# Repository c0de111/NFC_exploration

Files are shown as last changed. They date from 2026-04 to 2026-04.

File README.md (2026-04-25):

# NFC exploration

Sandbox repo to explore **ST25DV04KC (ISO15693 / NFC-V)** tap-to-trigger flows for power control and waking circuits such as inki.

## Goal
Build a small, reproducible test platform (ST25DV04KC + **Raspberry Pi Pico/RP2040** + antenna + simple enclosure) to validate:
- RF-field / `V_EH` wake behavior in the real case
- Phone → tag writes (EEPROM / Type 5)
- MCU reads request over I²C and clears/acks
- End-to-end timing assumptions for a future “tap-to-book” workflow

## Current validated behavior
- ST25DV04KC bring-up over I2C is stable on Pico (`GP20/GP21`), with ST25 power switched by `GP18`.
- End-to-end NFC-V write from phone to tag user memory is working.
- Firmware parses 16-byte `INKI` request payloads from the last user-memory slot (`0x01F0` on ST25DV04KC).
- Firmware command opcode handling is active:
  - `0x11` -> `LED1` slow blink
  - `0x12` -> `LED1` fast blink (same onboard LED)
  - `0x01` -> legacy alias mapped to `LED1` slow blink
- Incomplete/invalid `INKI` frames are ignored (to avoid partial-write races).
- Valid requests are cleared only after `RF field` goes `OFF` (reduces interference with phone-side readback).
- Power latch is asserted early by Pico on boot (`GP28`) and auto-released after `NFC_AUTO_POWER_OFF_MS` (default `10000` ms).
- Runtime logging is event-driven: startup diagnostics once, then RF field edges and request actions only.

## Tuning firmware (antenna / power characterization)
A dedicated firmware (`nfc_tune`, source: `firmware/src/tune_main.c`) for real-time RF energy-harvesting characterization. It samples the ST25DV `V_EH` output via Pico ADC and renders a live scrolling bar graph in the terminal showing harvested power delta above baseline.

### What it measures
- ADC voltage on `V_EH` pin (default ADC1 = `GP27`), averaged and EMA-smoothed
- Delta above a startup baseline capture (no-RF reference)
- RF field state derived from voltage thresholds (configurable ON/OFF hysteresis)
- ST25 EH control register state (`EH_EN`, `EH_ON`, `FIELD_ON`, `VCC_ON`) via I2C

### Build and flash
```bash
make firmware-tune                    # build nfc_tune
# then either:
make firmware-tune-flash              # flash via SWD
# or drag-and-drop firmware/build/nfc_tune.uf2 in BOOTSEL mode
```

### Tuning workflow
1. Connect Pico via USB (serial + power).
2. Open terminal: `sudo tio /dev/ttyACM0`
3. Wait for baseline capture (keep RF away for ~2 seconds at boot).
4. Tap phone to antenna — the live graph shows `V_EH` delta in mV, RF ON/OFF transitions, session peak, and EH register state.
5. Adjust antenna matching (C2/C3 on `NFC_harness_V0`) and re-tap to compare coupling.
6. `Ctrl+C` to stop.

### Key CMake tuning parameters
All defaults are in `firmware/CMakeLists.txt`:
- `NFC_TUNE_ADC_INPUT` – ADC channel (default `1` = `GP27`)
- `NFC_TUNE_FIELD_ON_MV` / `NFC_TUNE_FIELD_OFF_MV` – RF detection hysteresis thresholds (default `9` / `4` mV)
- `NFC_TUNE_GRAPH_WIDTH` / `NFC_TUNE_GRAPH_HEIGHT` – terminal graph dimensions (default `72x20`)
- `NFC_TUNE_GRAPH_MAX_MV` – vertical scale (default `3000` mV)
- `NFC_TUNE_SAMPLE_COUNT` / `NFC_TUNE_REPORT_INTERVAL_MS` – samples per report and update rate

## Current Wake/Latch Circuitry (PCB: `NFC_harness_V0`)
- `Q1` (`TSM260P02CX`, P-MOS) is the high-side power switch:
  - source -> `Vbatt`
  - drain -> Pico `VSYS`
- ST25 `GPO_(OPEN_DRAIN)` and the `Q1` gate share the same control net (wake/power-on net).
- Gate network shaping:
  - `R4=1M` pull-up to `Vbatt`
  - `C5=22n` to GND (pulse shaping / hold)
- Pico latch-hold path:
  - Pico `GPIO28` (`NFC_POWER_HOLD_PIN`) -> `R5=100k` -> `Q2` base
  - `R9=50k` pulls base to GND
  - `Q2` collector also sinks the same gate-control net
- On this PCB revision, Pico `GPIO19` is unconnected.
- LED wiring status on this PCB revision:
  - Both blink commands (`0x11` slow, `0x12` fast) use the firmware power-LED output (onboard Pico/Pico W path).
  - `NFC_STATUS_LED_PIN` (default `GP15`) is currently not routed to a dedicated onboard LED footprint here (external LED/wire may be needed).

## Command Flow (Phone -> ST25 -> Pico)
1. Board is fully off (`Vbatt` connected, no USB, Pico unpowered).
2. Phone tap powers ST25 RF side and writes the 16-byte `INKI` payload (including opcode byte) over NFC-V into ST25 EEPROM, while Pico can still be fully off.
3. ST25 asserts `GPO` low on configured wake event (`RF_WRITE`), pulling `Q1` gate low and powering Pico.
4. Pico boots and immediately asserts `GPIO28` high to latch power through `Q2`.
5. Data transfer from ST25 to Pico happens after boot over I2C (not on GPO):
   - Pico powers ST25 VCC via `GP18`
   - firmware reads request bytes from the last ST25 user-memory slot
6. Firmware validates the payload, applies opcode behavior, queues clear for RF-OFF, and later clears the slot.
7. Firmware releases the latch after timeout (`NFC_AUTO_POWER_OFF_MS`, default `10000` ms; re-armed on accepted commands).

Note:
- Runtime-loop request processing still runs while RF field is ON, with clear deferred to RF field OFF.
- Additionally, at boot firmware now checks for a stored valid request. If RF field is already OFF, it applies the command immediately and clears it at boot.
- If no valid `INKI` request is found after wake and RF is already OFF, firmware releases the power latch immediately.

## Repository layout
- `docs/context.md` – running notes, decisions, history, and solved problems
- `firmware/` – Pico SDK firmware scaffold (RP2040) for ST25 I²C exploration  
  - `src/` app entry (`main.c` harness, `tune_main.c` tuning) and bus adapter
  - `third_party/st25dv/` vendored ST25DV driver (git subtree)  
  - `scripts/` build/flash/reset helpers  
  - `cmake/` Pico SDK import helper  
- `pcb/NFC_harness_V0/` – KiCad project (schematic, layout, CAM profile)
- `pcb/tools/run_pcb2gcode.sh` – shared pcb2gcode runner
- `pcb/components/` + `pcb/project-libraries/` – KiCad symbols/footprints (includes ST25DV package lib submodule)
- `datasheet/` – ST25DV04KC datasheet + app notes
- `android/` – NFC‑V test apps (writer + hello) *(not needed for Pico-only workflow)*

## Typical workflow (from repo root)
1) **Build firmware**: `make firmware` (uses `PICO_SDK_PATH`, default `$HOME/pico/pico-sdk`).
2) **Flash**:  
   - Drag‑and‑drop: copy `firmware/build/nfc_harness.uf2` to Pico in BOOTSEL mode, or  
   - SWD: `make firmware-flash` (OpenOCD + CMSIS-DAP).
3) **Iterate**: edit `firmware/src/main.c` (and future helpers), rebuild, and re‑flash.
4) **CAM / milling** (optional): `pcb/tools/run_pcb2gcode.sh -b NFC_harness_V0` to regenerate toolpaths.

## Build & flash (Pico / RP2040)

### Build
```bash
# from repo root (recommended)
make firmware

# or inside firmware/
cd firmware
./scripts/build.sh   # expects $PICO_SDK_PATH (defaults to $HOME/pico/pico-sdk)
```
More detail (pin overrides, UF2 path, picotool toggles): see `firmware/README.md`.

Notes:
- Picotool is disabled by default to avoid downloads. The build script auto-fetches `uf2conv.py` (Microsoft UF2 tool) on first run and converts `nfc_harness.bin` → `nfc_harness.uf2`.
- Set `-DPICO_NO_PICOTOOL=OFF` in `cmake` if you prefer the picotool UF2/signing path.

Clean build artifacts:
```bash
make clean   # removes firmware/build only
```

Flash options:
- **USB drag‑and‑drop**: copy `firmware/build/nfc_harness.uf2` to the Pico mass‑storage device (BOOTSEL).
- **SWD (OpenOCD + CMSIS‑DAP probe)**:
  ```bash
  cd firmware
  ./scripts/flash.sh
  ```

### Root make targets (quick reference)
- `make firmware` – configure & build firmware into `firmware/build/`
- `make firmware-tune` – build dedicated antenna tuning firmware (`nfc_tune`)
- `make firmware-flash` – flash over SWD (OpenOCD + CMSIS‑DAP)
- `make firmware-tune-flash` – flash tuning firmware ELF over SWD
- `make clean` – remove `firmware/build/` only

## CAM workflow (pcb2gcode)
From repo root:
```bash
pcb/tools/run_pcb2gcode.sh -b NFC_harness_V0
```
The profile lives at `pcb/NFC_harness_V0/cam/pcb2gcode/profiles/default.millprojects` and uses repo-relative paths.

## Quick RF test (phone + Pico)
1. Connect a loop antenna to `J3` (`AC0`/`AC1`) on the PCB.
2. Build and flash firmware:
   - `make firmware`
   - copy `firmware/build/nfc_harness.uf2` to Pico in BOOTSEL mode (or use SWD).
3. Open serial logs:
   - `sudo tio /dev/ttyACM0`
4. On phone, open the NFC-V app (`inki`):
   - pick command button: `LED1 Slow` or `LED2 Fast`
5. Tap phone to antenna and hold briefly.

Expected runtime log pattern:
- `RF field: ON`
- `Request@0x01F0: ...`
- `INKI request: version=... opcode=... duration_min=...`
- `Command applied: opcode=... -> ...`
- `Queued clear after RF field OFF`
- `RF field: OFF`
- `Cleared request after RF OFF (...)`
- `Auto power-off: GP28 -> LOW`

Sample serial log (successful run):
```text
[INFO] RF field: OFF
[INFO] RF field: ON
[INFO] Request@0x01F0: 49 4E 4B 49 01 11 3C 00 ...
[OK] INKI request: version=1 opcode=0x11 duration_min=60 unix=... nonce=...
[OK] Command applied: opcode=0x11 -> LED1 slow blink
[INFO] Queued clear after RF field OFF
[INFO] RF field: OFF
[OK] Cleared request after RF OFF (16 bytes @ 0x01F0, attempts=1, 8ms)
[WARN] Auto power-off: GP28 -> LOW
```

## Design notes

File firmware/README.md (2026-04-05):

# Firmware (Pico / RP2040)

Pico-only firmware scaffold for the NFC harness.

It uses:
- **Pico SDK** (external dependency): toolchain integration + RP2040 libs (`hardware_i2c`, `pico_stdlib`, UF2 generation, …).
- **ST25DV driver** (vendored code): ST’s `stm32-st25dv` sources live in `third_party/st25dv/` (git subtree).

The ST driver is **not** part of the Pico SDK. It’s compiled into the firmware and talks to the Pico SDK I²C API through a small adapter layer (`ST25DV_IO_t`) implemented in `src/main.c` and `src/tune_main.c`.

## Layout
```
firmware/
  src/               # app entrypoints + bus adapters (`main.c`, `tune_main.c`)
  include/           # project headers (empty placeholder for now)
  third_party/st25dv # vendored ST25DV driver (subtree)
  cmake/             # pico_sdk_import.cmake
  scripts/           # build/flash helpers
  build/             # generated (gitignored)
```

## Dependencies (host)
- CMake + Make/Ninja
- `arm-none-eabi-gcc` toolchain
- `pico-sdk` checkout on disk (default path: `$HOME/pico/pico-sdk`)

## Build
```bash
# from repo root
make firmware
make firmware-tune

# or inside firmware/
cd firmware
./scripts/build.sh
./scripts/build.sh --target tune
```

`scripts/build.sh` passes `NFC_AUTO_POWER_OFF_MS` into CMake; default is `10000` ms (override per build, e.g. `NFC_AUTO_POWER_OFF_MS=5000 make firmware`).
By default it builds `nfc_harness`; use `--target tune` to build `nfc_tune`.

Picotool is disabled by default to avoid fetching/building it. On first run the build script downloads `uf2conv.py` and `uf2families.json` (Microsoft UF2 tool) into `firmware/scripts/` and converts `<target>.bin` → `<target>.uf2` without picotool. To re-enable picotool-based UF2/signing instead, configure CMake with `-DPICO_NO_PICOTOOL=OFF -DPICO_NO_UF2=OFF`.

Clean build directory (no rebuild):
```bash
make clean
# or
cd firmware && ./scripts/build.sh --clean
```

You can override common settings via CMake cache variables:
```bash
cd firmware
cmake -S . -B build -DPICO_BOARD=pico_w -DNFC_I2C_SDA_PIN=20 -DNFC_I2C_SCL_PIN=21 -DNFC_STATUS_LED_PIN=15 -DNFC_POWER_HOLD_PIN=28 -DNFC_ST25_VCC_EN_PIN=18 -DNFC_ST25_POWER_ON_DELAY_MS=10 -DNFC_ENABLE_WAKE_GPO_CONFIG=1 -DNFC_ENABLE_STARTUP_DIAGNOSTICS=1 -DNFC_ENABLE_BOOT_RW_TIMING_TEST=1
cmake --build build -j
```

`NFC_POWER_LED_PIN` controls a dedicated power-indicator LED (default `25`, Pico onboard LED). It is set ON at boot and stays ON while firmware is running; set `-DNFC_POWER_LED_PIN=-1` to disable.
On `pico_w`, the onboard LED is not on RP2040 GPIO; firmware uses CYW43 LED control when built with `PICO_BOARD=pico_w`.

By default the firmware drives `NFC_ST25_VCC_EN_PIN` high (`GP18`) and waits `NFC_ST25_POWER_ON_DELAY_MS` before ST25 I2C accesses. Set `-DNFC_ST25_VCC_EN_PIN=-1` if ST25 VCC is always powered externally.
`NFC_POWER_HOLD_PIN` (default `28`) is asserted high very early at boot so external latch circuitry can keep the board powered after an NFC-triggered wake pulse.
`NFC_ENABLE_WAKE_GPO_CONFIG=1` configures ST25 GPO for wake source `RF_WRITE` and sets longest pulse (`IT_TIME=0`, ~302 us) during startup.
`NFC_WAKE_GPO_SELFTEST_STRICT=0` keeps startup `SELFTEST` non-fatal for transient wake-GPO boot configuration failures (recommended while validating real wake behavior). Set it to `1` if you want strict bring-up gating.
At boot it also runs diagnostics (I2C address probe, dynamic status registers, self-test summary). Set `-DNFC_ENABLE_STARTUP_DIAGNOSTICS=0` for production-style minimal boot logs. `NFC_ENABLE_BOOT_RW_TIMING_TEST=1` enables a one-shot request-slot write/read/restore timing test (auto-skipped if a live `INKI` request is present).
`NFC_AUTO_POWER_OFF_MS` controls automatic latch release timeout (default `10000` ms). Set `0` to disable automatic power-off.
`NFC_LED_SLOW_PERIOD_MS` and `NFC_LED_FAST_PERIOD_MS` control blink periods for command-driven LED modes.

## Flash
- **USB drag‑and‑drop**: copy `build/nfc_harness.uf2` (or `build/nfc_tune.uf2`) onto the Pico in BOOTSEL mode.
- **SWD (OpenOCD + CMSIS‑DAP probe)**:
  ```bash
  cd firmware
  ./scripts/flash.sh
  ./scripts/flash.sh ./build/nfc_tune.elf
  ```

## Tuning firmware (`nfc_tune`)
`nfc_tune` is a dedicated antenna-tuning build that keeps the main Android/tap flow untouched:
- Boots Pico and ST25 (`GP18` power enable).
- Enables ST25 energy harvesting mode (`EH_MODE=ACTIVE_AFTER_BOOT`, `EH_EN=ON`).
- Samples ADC continuously and performs live RF detection from `V_EH`:
  - Startup baseline capture (no RF expected).
  - EMA smoothing.
  - Hysteresis thresholds (`ON` / `OFF`) with debounce for stable field state.
  - Active EH enforcement: retries `EH_EN` enable at boot and periodically re-checks during runtime.
  - Runtime EH re-arm: if field is present but `EH_ON=0`, firmware re-arms EH and re-validates state.
  - Hard requirement at boot: firmware stops if `EH_EN` cannot be latched.
  - Per-session peak delta tracking to tune coil turns and trimmer.
  - ANSI color bar graph panel (`20` rows by default) updated in place with no terminal scroll.
  - Legacy single-line status remains below the graph (`RF/raw/v/ema/base/d/peak/sess/EH`).

Default tuning options:
- `NFC_TUNE_ADC_INPUT=1` (`GPIO27` / Pico pin `32` / ADC1)
- `NFC_TUNE_SAMPLE_COUNT=256`
- `NFC_TUNE_REPORT_INTERVAL_MS=100`
- `NFC_TUNE_SAMPLE_DELAY_US=20`
- `NFC_TUNE_EMA_ALPHA=0.50`
- `NFC_TUNE_BASELINE_SAMPLES=4000`
- `NFC_TUNE_BASELINE_SETTLE_MS=400`
- `NFC_TUNE_FIELD_ON_MV=9`
- `NFC_TUNE_FIELD_OFF_MV=4`
- `NFC_TUNE_DEBOUNCE_COUNT=1`
- `NFC_TUNE_BASELINE_TRACK_ALPHA=0.01`
- `NFC_TUNE_FREEZE_BASELINE=1` (`1` = freeze startup baseline; `0` = slow tracking while `RF=OFF`)
- `NFC_TUNE_GRAPH_WIDTH=72`
- `NFC_TUNE_GRAPH_HEIGHT=20`
- `NFC_TUNE_GRAPH_MAX_MV=3000`
- `NFC_TUNE_EH_ENFORCE_RETRIES=8`
- `NFC_TUNE_EH_ENFORCE_RETRY_MS=20`
- `NFC_TUNE_EH_RECHECK_MS=1000`

Override example:
```bash
cd firmware
cmake -S . -B build \
  -DNFC_TUNE_ADC_INPUT=1 \
  -DNFC_TUNE_SAMPLE_COUNT=512 \
  -DNFC_TUNE_REPORT_INTERVAL_MS=150 \
  -DNFC_TUNE_FIELD_ON_MV=28 \
  -DNFC_TUNE_FIELD_OFF_MV=12 \
  -DNFC_TUNE_FREEZE_BASELINE=1
cmake --build build --target nfc_tune -j
```

## What it does
`main.c` initializes I²C, brings up the ST25DV driver, reads the last 16 bytes of user memory (where the Android app writes the `INKI` request), applies the command opcode, and clears the request when present.

Current opcode mapping:
- `0x11` (and legacy `0x01`) -> LED1 slow blink
- `0x12` -> LED1 fast blink (single onboard LED on current PCB)

For ST25DV, you typically expect these 7‑bit I²C addresses:
- `0x53` (user memory + dynamic regs)
- `0x57` (system memory)

## How the Pico SDK + ST driver fit together
- **Build system**: `CMakeLists.txt` builds two targets (`nfc_harness`, `nfc_tune`) and links Pico SDK + ST driver sources from `third_party/st25dv/`.
- **Pico SDK include**: `cmake/pico_sdk_import.cmake` finds your local `pico-sdk` (via `PICO_SDK_PATH`) and pulls in its CMake helpers.
- **ST driver include**: `third_party/st25dv/st25dv.c` and `third_party/st25dv/st25dv_reg.c` are compiled into the firmware and their headers are added to the include path.
- **Bus adapter**: `src/main.c` provides `ST25DV_IO_t` callbacks (`Init/Read/Write/IsReady/GetTick`) implemented using Pico SDK I²C calls. The ST driver stays “platform-agnostic” and calls into these callbacks.
- **Driver entrypoints**: `src/main.c` uses `St25Dv_Drv.*` (the driver’s exported API table). Some internal `ST25DV_*` functions exist in the sources but are not declared in the public header.

### Addressing note (7-bit vs 8-bit)
ST’s driver uses “8-bit I²C addresses” like `0xA6/0xAE` (includes the R/W bit in the LSB).
Pico SDK expects a **7-bit** address. The adapter shifts by 1 (`addr7 = addr8 >> 1`).

## Updating the ST driver subtree
This repo vendors the driver as a **squashed git subtree** (not a submodule).

Upstream:
- Local clone: `/home/nicolas/github/stm32-st25dv`
- Upstream URL: `https://github.com/STMicroelectronics/stm32-st25dv`
- Currently imported tag: `v2.0.2`

Update command:
```bash
git subtree pull --prefix=firmware/third_party/st25dv /home/nicolas/github/stm32-st25dv v2.0.2 --squash
```

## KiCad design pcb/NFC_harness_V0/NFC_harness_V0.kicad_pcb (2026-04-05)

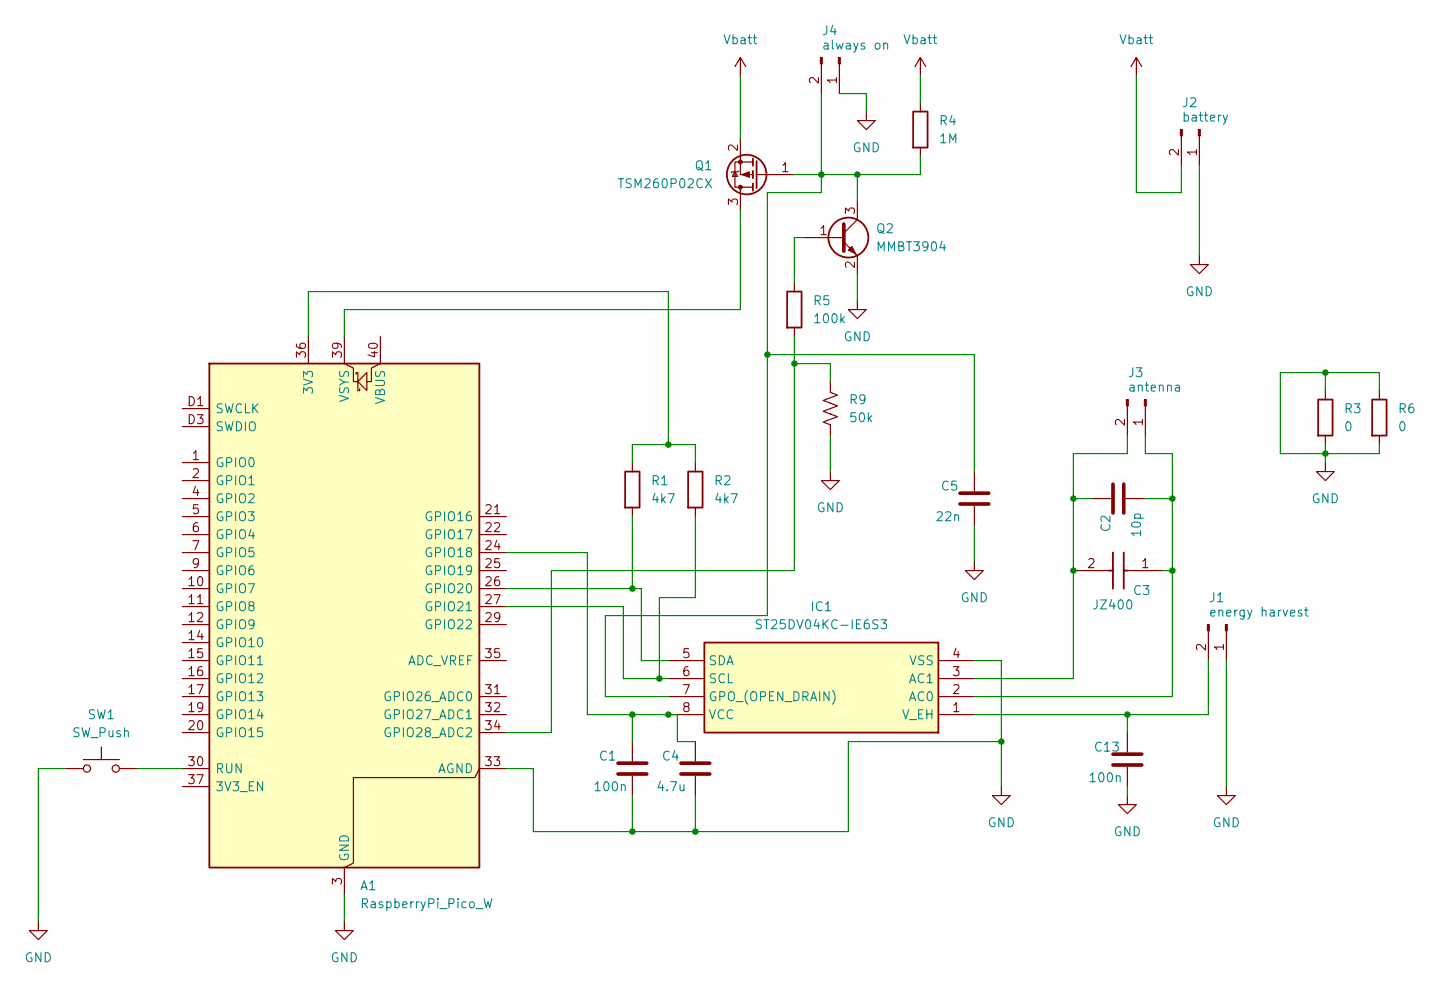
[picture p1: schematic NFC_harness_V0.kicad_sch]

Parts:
A1: RaspberryPi_Pico_W; RaspberryPi_Pico_W_SMD
C1, C13: 100n; C_0805_2012Metric
C2: 10p; C_0805_2012Metric
C3: JZ400; Mouser Part Number 768-JZ400
C4: 4.7u; C_1206_3216Metric
C5: 22n; C_0805_2012Metric
IC1: ST25DV04KC-IE6S3; SOIC127P600X175-8N; Mouser Part Number 511-ST25DV04KC-IE6S3
J1: energy harvest; PinHeader_1x02_P2.54mm_Vertical
J2: battery; PinHeader_1x02_P2.54mm_Vertical
J3: antenna; PinHeader_1x02_P2.54mm_Vertical
J4: always on; PinHeader_1x02_P2.54mm_Vertical
Q1: TSM260P02CX; SOT-23_Handsoldering
Q2: MMBT3904; SOT-23
R1, R2: 4k7; Fuse_1206_3216Metric_Pad1.42x1.75mm_HandSolder
R3, R6: 0; Fuse_1206_3216Metric_Pad1.42x1.75mm_HandSolder
R4: 1M; R_0805_2012Metric_Pad1.20x1.40mm_HandSolder
R5: 100k; Fuse_1206_3216Metric_Pad1.42x1.75mm_HandSolder
R9: 50k; Fuse_1206_3216Metric_Pad1.42x1.75mm_HandSolder
SW1: SW_Push; Taster 9313

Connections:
GND: A1.3 (GND), A1.8 (GND), A1.13 (GND), A1.18 (GND), A1.23 (GND), A1.28 (GND), A1.33 (AGND), A1.38 (GND), A1.D2 (GND), C1.2, C4.2, C5.2, C13.2, IC1.4 (VSS), J1.1, J2.1, J4.1, Q2.2 (E), R3.1, R3.2, R6.1, R6.2, R9.2, SW1.1
unnamed: A1.36 (3V3), R1.1, R2.1
unnamed: A1.24 (GPIO18), C1.1, C4.1, IC1.8 (VCC)
unnamed: A1.26 (GPIO20), IC1.5 (SDA), R1.2
unnamed: A1.27 (GPIO21), IC1.6 (SCL), R2.2
unnamed: A1.34 (GPIO28_ADC2), R5.2, R9.1
unnamed: A1.30 (RUN), SW1.2
unnamed: A1.39 (VSYS), Q1.3 (D)
unnamed: C2.2, C3.1, IC1.2 (AC0), J3.1
unnamed: C2.1, C3.2, IC1.3 (AC1), J3.2
unnamed: C5.1, IC1.7 (GPO_(OPEN_DRAIN)), J4.2, Q1.1 (G), Q2.3 (C), R4.2
unnamed: C13.1, IC1.1 (V_EH), J1.2
unnamed: Q2.1 (B), R5.1
Vbatt: J2.2, Q1.2 (S), R4.1

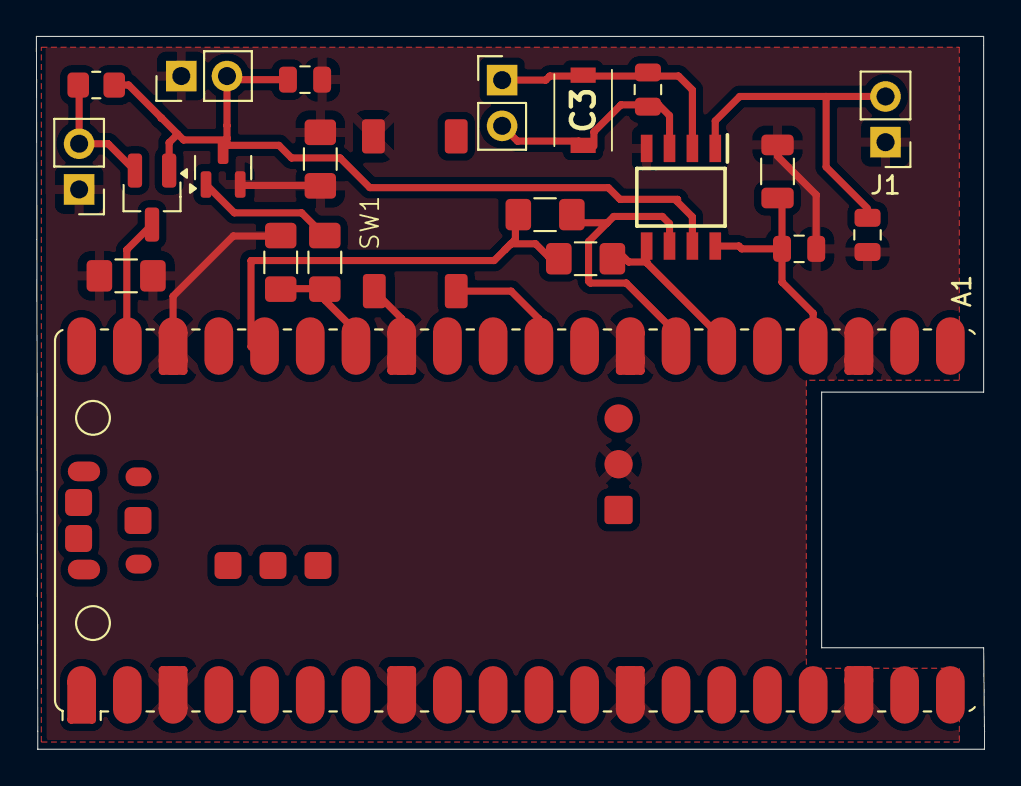
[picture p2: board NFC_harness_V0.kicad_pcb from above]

Board: 2 copper layers, 52.7 x 39.6 mm, 22 parts (0 on the bottom side), 14 nets.

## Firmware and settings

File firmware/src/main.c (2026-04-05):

#include <string.h>
#include <stdio.h>
#include <stdarg.h>

#include "hardware/i2c.h"
#include "pico/stdlib.h"
#if NFC_HAS_CYW43
#include "pico/cyw43_arch.h"
#endif

#include "st25dv.h"

#ifndef NFC_HAS_CYW43
#define NFC_HAS_CYW43 0
#endif

#ifndef NFC_I2C_INSTANCE
#define NFC_I2C_INSTANCE i2c0
#endif

#ifndef NFC_I2C_BAUDRATE_HZ
#define NFC_I2C_BAUDRATE_HZ 100000
#endif

#ifndef NFC_I2C_SDA_PIN
#define NFC_I2C_SDA_PIN 20
#endif

#ifndef NFC_I2C_SCL_PIN
#define NFC_I2C_SCL_PIN 21
#endif

#ifndef NFC_STATUS_LED_PIN
#define NFC_STATUS_LED_PIN 15
#endif

#ifndef NFC_POWER_LED_PIN
#define NFC_POWER_LED_PIN 25
#endif

#ifndef NFC_POWER_HOLD_PIN
#define NFC_POWER_HOLD_PIN 28
#endif

#ifndef NFC_ST25_VCC_EN_PIN
#define NFC_ST25_VCC_EN_PIN 18
#endif

#ifndef NFC_ST25_POWER_ON_DELAY_MS
#define NFC_ST25_POWER_ON_DELAY_MS 10
#endif

#ifndef NFC_ENABLE_BOOT_RW_TIMING_TEST
#define NFC_ENABLE_BOOT_RW_TIMING_TEST 1
#endif

#ifndef NFC_ENABLE_STARTUP_DIAGNOSTICS
#define NFC_ENABLE_STARTUP_DIAGNOSTICS 1
#endif

#ifndef NFC_ENABLE_EH_TEST_MODE
#define NFC_ENABLE_EH_TEST_MODE 1
#endif

#ifndef NFC_I2C_OP_TIMEOUT_US
#define NFC_I2C_OP_TIMEOUT_US 20000
#endif

#ifndef NFC_ENABLE_WAKE_GPO_CONFIG
#define NFC_ENABLE_WAKE_GPO_CONFIG 1
#endif

#ifndef NFC_WAKE_GPO_SELFTEST_STRICT
#define NFC_WAKE_GPO_SELFTEST_STRICT 0
#endif

#ifndef NFC_AUTO_POWER_OFF_MS
#define NFC_AUTO_POWER_OFF_MS 10000
#endif

#ifndef NFC_LED_SLOW_PERIOD_MS
#define NFC_LED_SLOW_PERIOD_MS 800
#endif

#ifndef NFC_LED_FAST_PERIOD_MS
#define NFC_LED_FAST_PERIOD_MS 150
#endif

#define INKI_OPCODE_BOOK_NOW 0x01u
#define INKI_OPCODE_LED1_SLOW 0x11u
#define INKI_OPCODE_LED2_FAST 0x12u

#define COLOR_RESET "\033[0m"
#define COLOR_RED "\033[31m"
#define COLOR_GREEN "\033[32m"
#define COLOR_YELLOW "\033[33m"
#define COLOR_CYAN "\033[36m"
#define COLOR_BOLD_RED "\033[1;31m"
#define COLOR_BOLD_GREEN "\033[1;32m"
#define COLOR_BOLD_YELLOW "\033[1;33m"

static void log_vcolor(const char* color, const char* tag, const char* fmt, va_list args) {
  printf("%s[%s]%s ", color, tag, COLOR_RESET);
  vprintf(fmt, args);
}

static void log_color(const char* color, const char* tag, const char* fmt, ...) {
  va_list args;
  va_start(args, fmt);
  log_vcolor(color, tag, fmt, args);
  va_end(args);
}

static void log_info(const char* fmt, ...) {
  va_list args;
  va_start(args, fmt);
  log_vcolor(COLOR_CYAN, "INFO", fmt, args);
  va_end(args);
}

static void log_ok(const char* fmt, ...) {
  va_list args;
  va_start(args, fmt);
  log_vcolor(COLOR_BOLD_GREEN, "OK", fmt, args);
  va_end(args);
}

static void log_warn(const char* fmt, ...) {
  va_list args;
  va_start(args, fmt);
  log_vcolor(COLOR_BOLD_YELLOW, "WARN", fmt, args);
  va_end(args);
}

static void log_err(const char* fmt, ...) {
  va_list args;
  va_start(args, fmt);
  log_vcolor(COLOR_BOLD_RED, "ERR", fmt, args);
  va_end(args);
}

static void i2c_setup(void) {
  i2c_init(NFC_I2C_INSTANCE, NFC_I2C_BAUDRATE_HZ);
  gpio_set_function(NFC_I2C_SDA_PIN, GPIO_FUNC_I2C);
  gpio_set_function(NFC_I2C_SCL_PIN, GPIO_FUNC_I2C);
  gpio_pull_up(NFC_I2C_SDA_PIN);
  gpio_pull_up(NFC_I2C_SCL_PIN);
}

static void st25_power_on(void) {
#if (NFC_ST25_VCC_EN_PIN >= 0)
  gpio_init(NFC_ST25_VCC_EN_PIN);
  gpio_set_dir(NFC_ST25_VCC_EN_PIN, GPIO_OUT);
  gpio_put(NFC_ST25_VCC_EN_PIN, 1);
#endif
}

static bool i2c_address_acks(uint8_t address_7bit) {
  const uint8_t probe_addr[2] = {0x00, 0x00};
  const int res = i2c_write_timeout_us(
      NFC_I2C_INSTANCE, address_7bit, probe_addr, (size_t)sizeof(probe_addr), false, NFC_I2C_OP_TIMEOUT_US);
  return res == (int)sizeof(probe_addr);
}

static uint8_t st25_addr7(uint16_t st_addr8) { return (uint8_t)(st_addr8 >> 1); }

static int32_t st25_bus_init(void) {
  i2c_setup();
  return 0;
}

static int32_t st25_bus_deinit(void) { return 0; }

static uint32_t st25_get_tick(void) { return (uint32_t)to_ms_since_boot(get_absolute_time()); }

static bool has_elapsed(uint32_t now_ms, uint32_t deadline_ms) {
  return ((int32_t)(now_ms - deadline_ms) >= 0);
}

static int32_t st25_is_ready(uint16_t dev_addr, const uint32_t trials) {
  const uint8_t addr7 = st25_addr7(dev_addr);
  for (uint32_t i = 0; i < trials; i++) {
    if (i2c_address_acks(addr7)) {
      return NFCTAG_OK;
    }
    sleep_ms(2);
  }
  return NFCTAG_NACK;
}

static int32_t st25_write(uint16_t dev_addr, uint16_t reg, const uint8_t* data, uint16_t len) {
  const uint8_t addr7 = st25_addr7(dev_addr);

  uint8_t tmp[2 + ST25DV_MAX_WRITE_BYTE];
  if (len > ST25DV_MAX_WRITE_BYTE) {
    return NFCTAG_ERROR;
  }

  tmp[0] = (uint8_t)((reg >> 8) & 0xFF);
  tmp[1] = (uint8_t)(reg & 0xFF);
  if (len > 0) {
    memcpy(&tmp[2], data, len);
  }

  const int res = i2c_write_timeout_us(NFC_I2C_INSTANCE, addr7, tmp, (size_t)(len + 2), false, NFC_I2C_OP_TIMEOUT_US);
  return (res < 0) ? NFCTAG_NACK : NFCTAG_OK;
}

static int32_t st25_read(uint16_t dev_addr, uint16_t reg, uint8_t* data, uint16_t len) {
  const uint8_t addr7 = st25_addr7(dev_addr);

  const uint8_t addr_buf[2] = {
      (uint8_t)((reg >> 8) & 0xFF),
      (uint8_t)(reg & 0xFF),
  };

  int res = i2c_write_timeout_us(NFC_I2C_INSTANCE, addr7, addr_buf, sizeof(addr_buf), true, NFC_I2C_OP_TIMEOUT_US);
  if (res < 0) {
    return NFCTAG_NACK;
  }

  res = i2c_read_timeout_us(NFC_I2C_INSTANCE, addr7, data, len, false, NFC_I2C_OP_TIMEOUT_US);
  return (res < 0) ? NFCTAG_NACK : NFCTAG_OK;
}

static void dump_hex(const uint8_t* buf, size_t len) {
  for (size_t i = 0; i < len; i++) {
    printf("%02X", buf[i]);
    if ((i + 1) != len) {
      printf(" ");
    }
  }
}

static bool is_inki_request(const uint8_t req16[16]) {
  return req16[0] == 'I' && req16[1] == 'N' && req16[2] == 'K' && req16[3] == 'I';
}

typedef struct {
  uint8_t version;
  uint8_t opcode;
  uint16_t duration_min;
  uint32_t unix_seconds;
  uint32_t nonce;
} InkiRequest;

static bool decode_inki_request(const uint8_t req16[16], InkiRequest* out) {
  if (!is_inki_request(req16)) {
    return false;
  }

  if (out != NULL) {
    out->version = req16[4];
    out->opcode = req16[5];
    out->duration_min = (uint16_t)req16[6] | ((uint16_t)req16[7] << 8);
    out->unix_seconds = (uint32_t)req16[8] | ((uint32_t)req16[9] << 8) |
                        ((uint32_t)req16[10] << 16) | ((uint32_t)req16[11] << 24);
    out->nonce = (uint32_t)req16[12] | ((uint32_t)req16[13] << 8) |
                 ((uint32_t)req16[14] << 16) | ((uint32_t)req16[15] << 24);
  }

  return true;
}

static bool validate_inki_request(const InkiRequest* req, const char** reason) {
  if (req->version != 1u) {
    if (reason != NULL) {
      *reason = "version";
    }
    return false;
  }
  if (req->opcode == 0u) {
    if (reason != NULL) {
      *reason = "opcode";
    }
    return false;
  }
  if (req->duration_min == 0u || req->duration_min > (24u * 60u)) {
    if (reason != NULL) {
      *reason = "duration";
    }
    return false;
  }
  if (req->unix_seconds == 0u) {
    if (reason != NULL) {
      *reason = "unix";
    }
    return false;
  }
  if (req->nonce == 0u) {
    if (reason != NULL) {
      *reason = "nonce";
    }
    return false;
  }
  return true;
}

static bool request_is_all_zero(const uint8_t req16[16]) {
  for (size_t i = 0; i < 16; i++) {
    if (req16[i] != 0) {
      return false;
    }
  }
  return true;
}

static void log_request_bytes(uint16_t addr, const uint8_t req16[16]) {
  printf("%s[INFO]%s Request@0x%04X: ", COLOR_CYAN, COLOR_RESET, addr);
  dump_hex(req16, 16);
  printf("\n");
}

static const char* st25_icref_name(uint8_t icref) {
  switch (icref) {
    case 0x24:
      return "ST25DV04 (legacy)";
    case 0x25:
      return "ST25DV04 CMOS (legacy)";
    case 0x26:
      return "ST25DV16/64 (legacy)";
    case 0x27:
      return "ST25DV16/64 CMOS (legacy)";
    case 0x50:
      return "ST25DV04KC";
    case 0x51:
      return "ST25DV16KC/ST25DV64KC";
    default:
      return "Unknown";
  }
}

static const char* st25_part_from_size(uint32_t total_bytes) {
  switch (total_bytes) {
    case 512:
      return "ST25DV04KC";
    case 2048:
      return "ST25DV16KC";
    case 8192:
      return "ST25DV64KC";
    default:
      return "Unknown capacity";
  }
}

static const char* st25_uid_product_code_name(uint8_t product_code) {
  switch (product_code) {
    case 0x50:
      return "ST25DV04KC-IE";
    case 0x51:
      return "ST25DV16KC/64KC-IE";
    case 0x52:
      return "ST25DV04KC-JF";
    case 0x53:
      return "ST25DV16KC/64KC-JF";
    default:
      return "Unknown product code";
  }
}

static const char* st25_eh_mode_name(ST25DV_EH_MODE_STATUS mode) {
  switch (mode) {
    case ST25DV_EH_ACTIVE_AFTER_BOOT:
      return "ACTIVE_AFTER_BOOT";
    case ST25DV_EH_ON_DEMAND:
      return "ON_DEMAND";
    default:
      return "UNKNOWN";
  }
}

static const char* st25_en_name(ST25DV_EN_STATUS status) {
  return (status == ST25DV_ENABLE) ? "ON" : "OFF";
}

static const char* st25_field_name(ST25DV_FIELD_STATUS status) {
  return (status == ST25DV_FIELD_ON) ? "ON" : "OFF";
}

static const char* st25_vcc_name(ST25DV_VCC_STATUS status) {
  return (status == ST25DV_VCC_ON) ? "ON" : "OFF";
}

static const char* st25_session_name(ST25DV_I2CSSO_STATUS status) {
  return (status == ST25DV_SESSION_OPEN) ? "OPEN" : "CLOSED";
}

static const char* st25_current_msg_name(ST25DV_CURRENT_MSG msg) {
  switch (msg) {
    case ST25DV_NO_MSG:
      return "NO_MSG";
    case ST25DV_HOST_MSG:
      return "HOST_MSG";
    case ST25DV_RF_MSG:
      return "RF_MSG";
    default:
      return "UNKNOWN";
  }
}

static void init_power_hold_early(void) {
#if (NFC_POWER_HOLD_PIN >= 0)
  gpio_init(NFC_POWER_HOLD_PIN);
  gpio_set_dir(NFC_POWER_HOLD_PIN, GPIO_OUT);
  gpio_put(NFC_POWER_HOLD_PIN, 1);
#endif
}

static uint32_t st25_it_pulse_us(ST25DV_PULSE_DURATION pulse) {
  switch (pulse) {
    case ST25DV_302_US:
      return 302u;
    case ST25DV_264_US:
      return 264u;
    case ST25DV_226_US:
      return 226u;
    case ST25DV_188_US:
      return 188u;
    case ST25DV_151_US:
      return 151u;
    case ST25DV_113_US:
      return 113u;
    case ST25DV_75_US:
      return 75u;
    case ST25DV_37_US:
      return 37u;
    default:
      return 0u;
  }
}

static int32_t st25_write_itpulse_retry(ST25DV_Object_t* st,
                                        ST25DV_PULSE_DURATION pulse,
                                        uint32_t timeout_ms,
                                        uint32_t retry_delay_ms,
                                        uint32_t* attempts) {
  const uint32_t t0 = st25_get_tick();
  uint32_t tries = 0;
  int32_t ret = NFCTAG_ERROR;

  do {
    tries++;
    ret = ST25DV_WriteITPulse(st, pulse);
    if (ret == NFCTAG_OK) {
      break;
    }
    sleep_ms(retry_delay_ms);
  } while ((st25_get_tick() - t0) < timeout_ms);

  if (attempts != NULL) {
    *attempts = tries;
  }
  return ret;
}

static int32_t st25_config_it_retry(ST25DV_Object_t* st,
                                    uint16_t it_conf,
                                    uint32_t timeout_ms,
                                    uint32_t retry_delay_ms,
                                    uint32_t* attempts) {
  const uint32_t t0 = st25_get_tick();
  uint32_t tries = 0;
  int32_t ret = NFCTAG_ERROR;

  do {
    tries++;
    ret = St25Dv_Drv.ConfigIT(st, it_conf);
    if (ret == NFCTAG_OK) {
      break;
    }
    sleep_ms(retry_delay_ms);
  } while ((st25_get_tick() - t0) < timeout_ms);

  if (attempts != NULL) {
    *attempts = tries;
  }
  return ret;
}

static int32_t st25_get_it_status_retry(ST25DV_Object_t* st,
                                        uint16_t* it_status,
                                        uint32_t timeout_ms,
                                        uint32_t retry_delay_ms,
                                        uint32_t* attempts) {
  const uint32_t t0 = st25_get_tick();
  uint32_t tries = 0;
  int32_t ret = NFCTAG_ERROR;

  do {
    tries++;
    ret = St25Dv_Drv.GetITStatus(st, it_status);
    if (ret == NFCTAG_OK) {
      break;
    }
    sleep_ms(retry_delay_ms);
  } while ((st25_get_tick() - t0) < timeout_ms);

  if (attempts != NULL) {
    *attempts = tries;
  }
  return ret;
}

static int32_t st25_read_eh_mode_retry(ST25DV_Object_t* st,
                                       ST25DV_EH_MODE_STATUS* eh_mode,
                                       uint32_t timeout_ms,
                                       uint32_t retry_delay_ms,
                                       uint32_t* attempts) {
  const uint32_t t0 = st25_get_tick();
  uint32_t tries = 0;
  int32_t ret = NFCTAG_ERROR;

  do {
    tries++;
    ret = ST25DV_ReadEHMode(st, eh_mode);
    if (ret == NFCTAG_OK) {
      break;
    }
    sleep_ms(retry_delay_ms);
  } while ((st25_get_tick() - t0) < timeout_ms);

  if (attempts != NULL) {
    *attempts = tries;
  }
  return ret;
}

static bool configure_wake_gpo(ST25DV_Object_t* st) {
#if NFC_ENABLE_WAKE_GPO_CONFIG
  bool ok = true;
  int32_t ret = NFCTAG_OK;
  const uint32_t cfg_timeout_ms = (uint32_t)ST25DV_WRITE_TIMEOUT + 50u;
  const uint32_t cfg_retry_delay_ms = 2u;
  uint32_t attempts = 0;

  ret = st25_write_itpulse_retry(st, ST25DV_302_US, cfg_timeout_ms, cfg_retry_delay_ms, &attempts);
  if (ret == NFCTAG_OK) {
    log_ok("Wake GPO pulse set: IT_TIME=0 (~302 us)\n");
    if (attempts > 1) {
      log_warn("Wake GPO pulse config retries: %lu\n", (unsigned long)attempts);
    }
  } else {
    log_err("Wake GPO pulse config failed after %lu attempt(s): %ld\n", (unsigned long)attempts, (long)ret);
    ok = false;
  }

  const uint16_t wake_conf = (uint16_t)(ST25DV_GPO_ENABLE_MASK | ST25DV_GPO_RFWRITE_MASK);
  ret = st25_config_it_retry(st, wake_conf, cfg_timeout_ms, cfg_retry_delay_ms, &attempts);
  if (ret == NFCTAG_OK) {
    log_ok("Wake GPO sources set: ENABLE + RF_WRITE\n");
    if (attempts > 1) {
      log_warn("Wake GPO source config retries: %lu\n", (unsigned long)attempts);
    }
  } else {
    log_err("Wake GPO source config failed after %lu attempt(s): %ld\n", (unsigned long)attempts, (long)ret);
    ok = false;
  }

  uint16_t gpo_status = 0;
  ret = st25_get_it_status_retry(st, &gpo_status, cfg_timeout_ms, cfg_retry_delay_ms, &attempts);
  if (ret == NFCTAG_OK) {
    log_info("Wake GPO config readback: 0x%02X\n", (unsigned)(gpo_status & 0xFFu));
    if (attempts > 1) {
      log_warn("Wake GPO readback retries: %lu\n", (unsigned long)attempts);
    }
  } else {
    log_warn("Wake GPO readback failed after %lu attempt(s): %ld\n", (unsigned long)attempts, (long)ret);
    ok = false;
  }

  return ok;
#else
  (void)st;
  log_info("Wake GPO config disabled (NFC_ENABLE_WAKE_GPO_CONFIG=0)\n");
  return true;
#endif
}

static void append_reason(char* reasons, size_t reasons_size, const char* reason) {
  if (reasons_size == 0 || reason == NULL || reason[0] == '\0') {
    return;
  }

  const size_t used = strlen(reasons);
  if (used >= reasons_size - 1) {
    return;
  }

  const char* sep = (used == 0) ? "" : ", ";
  (void)snprintf(reasons + used, reasons_size - used, "%s%s", sep, reason);
}

static bool print_i2c_probe_summary(void) {
  const bool ack_53 = i2c_address_acks(0x53);
  const bool ack_57 = i2c_address_acks(0x57);

  log_info("I2C probe (7-bit): 0x53=%s 0x57=%s\n", ack_53 ? "ACK" : "NACK", ack_57 ? "ACK" : "NACK");
  if (ack_53 && ack_57) {
    log_ok("I2C address probe passed\n");
  } else {
    log_warn("I2C address probe incomplete\n");
  }
  return ack_53 && ack_57;
}

static bool print_dynamic_status(ST25DV_Object_t* st) {
  bool all_ok = true;
  int32_t ret = NFCTAG_OK;

  ST25DV_I2CSSO_STATUS session = ST25DV_SESSION_CLOSED;
  ret = ST25DV_ReadI2CSecuritySession_Dyn(st, &session);
  if (ret == NFCTAG_OK) {
    log_info("DYN I2C session: %s (security session)\n", st25_session_name(session));
  } else {
    log_err("DYN I2C session read failed: %ld\n", (long)ret);
    all_ok = false;
  }

  ST25DV_EH_CTRL eh = {0};
  ret = ST25DV_ReadEHCtrl_Dyn(st, &eh);
  if (ret == NFCTAG_OK) {
    log_info("DYN EH: EH_EN=%s EH_ON=%s FIELD_ON=%s VCC_ON=%s (EH ctrl bits)\n",
             st25_en_name(eh.EH_EN_Mode),
             st25_en_name(eh.EH_on),
             st25_en_name(eh.Field_on),
             st25_en_name(eh.VCC_on));
  } else {
    log_err("DYN EH_CTRL read failed: %ld\n", (long)ret);
    all_ok = false;
  }

  ST25DV_FIELD_STATUS rf_field = ST25DV_FIELD_OFF;
  ret = ST25DV_GetRFField_Dyn(st, &rf_field);
  if (ret == NFCTAG_OK) {
    log_info("DYN RF field: %s (carrier detect)\n", st25_field_name(rf_field));
  } else {
    log_err("DYN RF field read failed: %ld\n", (long)ret);
    all_ok = false;
  }

  ST25DV_VCC_STATUS vcc = ST25DV_VCC_OFF;
  ret = ST25DV_GetVCC_Dyn(st, &vcc);
  if (ret == NFCTAG_OK) {
    log_info("DYN VCC seen by ST25: %s (tag VCC state)\n", st25_vcc_name(vcc));
  } else {
    log_err("DYN VCC status read failed: %ld\n", (long)ret);
    all_ok = false;
  }

  ST25DV_RF_MNGT rf_mngt = {0};
  ret = ST25DV_ReadRFMngt_Dyn(st, &rf_mngt);
  if (ret == NFCTAG_OK) {
    log_info("DYN RF mngt: RF_DISABLE=%s RF_SLEEP=%s (RF interface ctrl)\n",
             st25_en_name(rf_mngt.RfDisable),
             st25_en_name(rf_mngt.RfSleep));
  } else {
    log_err("DYN RF management read failed: %ld\n", (long)ret);
    all_ok = false;
  }

  uint8_t it_status = 0;
  ret = ST25DV_ReadITSTStatus_Dyn(st, &it_status);
  if (ret == NFCTAG_OK) {
    log_info("DYN IT status: 0x%02X (latched event bits)\n", it_status);
  } else {
    log_err("DYN IT status read failed: %ld\n", (long)ret);
    all_ok = false;
  }

  uint8_t gpo_dyn = 0;
  ret = ST25DV_ReadGPO_Dyn(st, &gpo_dyn);
  if (ret == NFCTAG_OK) {
    log_info("DYN GPO: 0x%02X (GPO dynamic reg)\n", gpo_dyn);
  } else {
    log_err("DYN GPO read failed: %ld\n", (long)ret);
    all_ok = false;
  }

  ST25DV_PULSE_DURATION it_pulse = ST25DV_188_US;
  ret = ST25DV_ReadITPulse(st, &it_pulse);
  if (ret == NFCTAG_OK) {
    log_info("DYN GPO IT pulse: IT_TIME=%u (~%lu us)\n",
             (unsigned)it_pulse,
             (unsigned long)st25_it_pulse_us(it_pulse));
  } else {
    log_err("DYN GPO IT pulse read failed: %ld\n", (long)ret);
    all_ok = false;
  }

  ST25DV_MB_CTRL_DYN_STATUS mb = {0};
  ret = ST25DV_ReadMBCtrl_Dyn(st, &mb);
  if (ret == NFCTAG_OK) {
    log_info("DYN mailbox: MBEN=%u HOSTPUT=%u RFPUT=%u HOSTMISS=%u RFMISS=%u CUR=%s (FTM status)\n",
             (unsigned)mb.MbEnable,
             (unsigned)mb.HostPutMsg,
             (unsigned)mb.RfPutMsg,
             (unsigned)mb.HostMissMsg,
             (unsigned)mb.RFMissMsg,
             st25_current_msg_name(mb.CurrentMsg));
  } else {
    log_err("DYN mailbox ctrl read failed: %ld\n", (long)ret);
    all_ok = false;
  }

  uint8_t mb_len = 0;
  ret = ST25DV_ReadMBLength_Dyn(st, &mb_len);
  if (ret == NFCTAG_OK) {
    log_info("DYN mailbox length: %u (FTM bytes)\n", (unsigned)mb_len);
  } else {
    log_err("DYN mailbox length read failed: %ld\n", (long)ret);
    all_ok = false;
  }

  if (all_ok) {
    log_ok("Dynamic status diagnostics passed\n");
  }
  return all_ok;
}

static bool configure_eh_test_mode(ST25DV_Object_t* st) {
  bool ok = true;
  int32_t ret = NFCTAG_OK;
  const uint32_t eh_verify_timeout_ms = (uint32_t)ST25DV_WRITE_TIMEOUT + 50u;
  const uint32_t eh_verify_retry_delay_ms = 2u;
  uint32_t eh_verify_attempts = 0;

  ST25DV_EH_MODE_STATUS eh_mode = ST25DV_EH_ACTIVE_AFTER_BOOT;
  ret = ST25DV_ReadEHMode(st, &eh_mode);
  if (ret == NFCTAG_OK) {
    log_info("EH mode (before): %s\n", st25_eh_mode_name(eh_mode));
  } else {
    log_warn("EH mode read failed: %ld\n", (long)ret);
    ok = false;
  }

  log_info("EH mode write request: ACTIVE_AFTER_BOOT\n");
  ret = ST25DV_WriteEHMode(st, ST25DV_EH_ACTIVE_AFTER_BOOT);
  if (ret == NFCTAG_OK) {
    log_ok("EH mode write: ACTIVE_AFTER_BOOT\n");
  } else {
    log_err("EH mode write failed: %ld\n", (long)ret);
    ok = false;
  }

  eh_mode = ST25DV_EH_ACTIVE_AFTER_BOOT;
  ret = st25_read_eh_mode_retry(st, &eh_mode, eh_verify_timeout_ms, eh_verify_retry_delay_ms, &eh_verify_attempts);
  if (ret == NFCTAG_OK) {
    log_info("EH mode (after): %s\n", st25_eh_mode_name(eh_mode));
    if (eh_verify_attempts > 1) {
      log_warn("EH mode verify retries: %lu\n", (unsigned long)eh_verify_attempts);
    }
    if (eh_mode != ST25DV_EH_ACTIVE_AFTER_BOOT) {
      log_warn("EH mode verify mismatch\n");
      ok = false;
    }
  } else {
    log_warn("EH mode verify read failed: %ld\n", (long)ret);
    ok = false;
  }

#if NFC_ENABLE_EH_TEST_MODE
  ret = ST25DV_SetEHENMode_Dyn(st);
  if (ret == NFCTAG_OK) {
    log_ok("EH test mode: dynamic EH_EN set ON\n");
  } else {
    log_err("EH test mode enable failed: %ld\n", (long)ret);
    ok = false;
  }
#else
  log_info("EH test mode disabled (NFC_ENABLE_EH_TEST_MODE=0)\n");
#endif

  ST25DV_EH_CTRL eh = {0};
  ret = ST25DV_ReadEHCtrl_Dyn(st, &eh);
  if (ret == NFCTAG_OK) {
    log_info("EH state: EH_EN=%s EH_ON=%s FIELD_ON=%s VCC_ON=%s\n",
             st25_en_name(eh.EH_EN_Mode),
             st25_en_name(eh.EH_on),
             st25_en_name(eh.Field_on),
             st25_en_name(eh.VCC_on));
  } else {
    log_warn("EH state read failed: %ld\n", (long)ret);
    ok = false;
  }

  return ok;
}
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
int main(void) {
  init_power_hold_early();

  stdio_init_all();
  sleep_ms(1500);

  boot_log_banner();
  init_led_and_st25_power();

  HarnessState state = {0};
  StartupDiag diag;
  RuntimeControl runtime;
  startup_diag_reset(&diag);

  if (!st25_register_bus(&state)) {
    fatal_blink_forever();
  }

  run_identity_and_memory_bringup(&state, &diag);
  run_optional_startup_diagnostics(&state, &diag);
  runtime_init(&runtime);
  if (!process_boot_stored_request(&state, &runtime)) {
    while (true) {
      sleep_ms(1000);
    }
  }
  poll_request_loop(&state, &runtime);
}

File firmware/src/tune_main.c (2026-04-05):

#include <stdbool.h>
#include <stdint.h>
#include <stdio.h>

#include "hardware/adc.h"
#include "hardware/i2c.h"
#include "pico/stdlib.h"

#include "st25dv.h"

#ifndef NFC_I2C_INSTANCE
#define NFC_I2C_INSTANCE i2c0
#endif

#ifndef NFC_I2C_BAUDRATE_HZ
#define NFC_I2C_BAUDRATE_HZ 100000
#endif

#ifndef NFC_I2C_SDA_PIN
#define NFC_I2C_SDA_PIN 20
#endif

#ifndef NFC_I2C_SCL_PIN
#define NFC_I2C_SCL_PIN 21
#endif

#ifndef NFC_POWER_HOLD_PIN
#define NFC_POWER_HOLD_PIN 28
#endif

#ifndef NFC_ST25_VCC_EN_PIN
#define NFC_ST25_VCC_EN_PIN 18
#endif

#ifndef NFC_ST25_POWER_ON_DELAY_MS
#define NFC_ST25_POWER_ON_DELAY_MS 10
#endif

#ifndef NFC_I2C_OP_TIMEOUT_US
#define NFC_I2C_OP_TIMEOUT_US 20000
#endif

#ifndef NFC_TUNE_ADC_INPUT
#define NFC_TUNE_ADC_INPUT 1
#endif

#ifndef NFC_TUNE_SAMPLE_COUNT
#define NFC_TUNE_SAMPLE_COUNT 256
#endif

#ifndef NFC_TUNE_REPORT_INTERVAL_MS
#define NFC_TUNE_REPORT_INTERVAL_MS 100
#endif

#ifndef NFC_TUNE_SAMPLE_DELAY_US
#define NFC_TUNE_SAMPLE_DELAY_US 20
#endif

#ifndef NFC_TUNE_EMA_ALPHA
#define NFC_TUNE_EMA_ALPHA 0.50f
#endif

#ifndef NFC_TUNE_BASELINE_SAMPLES
#define NFC_TUNE_BASELINE_SAMPLES 4000
#endif

#ifndef NFC_TUNE_FIELD_ON_MV
#define NFC_TUNE_FIELD_ON_MV 9.0f
#endif

#ifndef NFC_TUNE_FIELD_OFF_MV
#define NFC_TUNE_FIELD_OFF_MV 4.0f
#endif

#ifndef NFC_TUNE_DEBOUNCE_COUNT
#define NFC_TUNE_DEBOUNCE_COUNT 1
#endif

#ifndef NFC_TUNE_BASELINE_TRACK_ALPHA
#define NFC_TUNE_BASELINE_TRACK_ALPHA 0.01f
#endif

#ifndef NFC_TUNE_FREEZE_BASELINE
#define NFC_TUNE_FREEZE_BASELINE 1
#endif

#ifndef NFC_TUNE_GRAPH_WIDTH
#define NFC_TUNE_GRAPH_WIDTH 72
#endif

#ifndef NFC_TUNE_GRAPH_HEIGHT
#define NFC_TUNE_GRAPH_HEIGHT 20
#endif

#ifndef NFC_TUNE_GRAPH_MAX_MV
#define NFC_TUNE_GRAPH_MAX_MV 3000.0f
#endif

#ifndef NFC_TUNE_BASELINE_SETTLE_MS
#define NFC_TUNE_BASELINE_SETTLE_MS 400
#endif

#ifndef NFC_TUNE_EH_ENFORCE_RETRIES
#define NFC_TUNE_EH_ENFORCE_RETRIES 8
#endif

#ifndef NFC_TUNE_EH_ENFORCE_RETRY_MS
#define NFC_TUNE_EH_ENFORCE_RETRY_MS 20
#endif

#ifndef NFC_TUNE_EH_RECHECK_MS
#define NFC_TUNE_EH_RECHECK_MS 1000
#endif

#define COLOR_RESET "\033[0m"
#define COLOR_CYAN "\033[36m"
#define COLOR_GREEN "\033[32m"
#define COLOR_YELLOW "\033[33m"
#define COLOR_BLUE "\033[34m"
#define COLOR_RED "\033[31m"
#define COLOR_DIM "\033[2m"
#define COLOR_BOLD_GREEN "\033[1;32m"
#define COLOR_BOLD_YELLOW "\033[1;33m"
#define COLOR_BOLD_RED "\033[1;31m"
#define TERM_HIDE_CURSOR "\033[?25l"

static void i2c_setup(void) {
  i2c_init(NFC_I2C_INSTANCE, NFC_I2C_BAUDRATE_HZ);
  gpio_set_function(NFC_I2C_SDA_PIN, GPIO_FUNC_I2C);
  gpio_set_function(NFC_I2C_SCL_PIN, GPIO_FUNC_I2C);
  gpio_pull_up(NFC_I2C_SDA_PIN);
  gpio_pull_up(NFC_I2C_SCL_PIN);
}

static void init_power_hold_early(void) {
#if (NFC_POWER_HOLD_PIN >= 0)
  gpio_init(NFC_POWER_HOLD_PIN);
  gpio_set_dir(NFC_POWER_HOLD_PIN, GPIO_OUT);
  gpio_put(NFC_POWER_HOLD_PIN, 1);
#endif
}

static void st25_power_on(void) {
#if (NFC_ST25_VCC_EN_PIN >= 0)
  gpio_init(NFC_ST25_VCC_EN_PIN);
  gpio_set_dir(NFC_ST25_VCC_EN_PIN, GPIO_OUT);
  gpio_put(NFC_ST25_VCC_EN_PIN, 1);
#endif
}

static uint8_t st25_addr7(uint16_t st_addr8) { return (uint8_t)(st_addr8 >> 1); }

static int32_t st25_bus_init(void) {
  i2c_setup();
  return 0;
}

static int32_t st25_bus_deinit(void) { return 0; }

static uint32_t st25_get_tick(void) { return (uint32_t)to_ms_since_boot(get_absolute_time()); }

static int32_t st25_is_ready(uint16_t dev_addr, const uint32_t trials) {
  const uint8_t addr7 = st25_addr7(dev_addr);
  const uint8_t probe_addr[2] = {0x00, 0x00};

  for (uint32_t i = 0; i < trials; i++) {
    const int res = i2c_write_timeout_us(
        NFC_I2C_INSTANCE, addr7, probe_addr, (size_t)sizeof(probe_addr), false, NFC_I2C_OP_TIMEOUT_US);
    if (res == (int)sizeof(probe_addr)) {
      return NFCTAG_OK;
    }
    sleep_ms(2);
  }
  return NFCTAG_NACK;
}

static int32_t st25_write(uint16_t dev_addr, uint16_t reg, const uint8_t* data, uint16_t len) {
  const uint8_t addr7 = st25_addr7(dev_addr);

  uint8_t tmp[2 + ST25DV_MAX_WRITE_BYTE];
  if (len > ST25DV_MAX_WRITE_BYTE) {
    return NFCTAG_ERROR;
  }

  tmp[0] = (uint8_t)((reg >> 8) & 0xFF);
  tmp[1] = (uint8_t)(reg & 0xFF);
  for (uint16_t i = 0; i < len; i++) {
    tmp[2 + i] = data[i];
  }

  const int res = i2c_write_timeout_us(NFC_I2C_INSTANCE, addr7, tmp, (size_t)(len + 2), false, NFC_I2C_OP_TIMEOUT_US);
  return (res < 0) ? NFCTAG_NACK : NFCTAG_OK;
}

static int32_t st25_read(uint16_t dev_addr, uint16_t reg, uint8_t* data, uint16_t len) {
  const uint8_t addr7 = st25_addr7(dev_addr);
  const uint8_t addr_buf[2] = {
      (uint8_t)((reg >> 8) & 0xFF),
      (uint8_t)(reg & 0xFF),
  };

  int res = i2c_write_timeout_us(NFC_I2C_INSTANCE, addr7, addr_buf, sizeof(addr_buf), true, NFC_I2C_OP_TIMEOUT_US);
  if (res < 0) {
    return NFCTAG_NACK;
  }

  res = i2c_read_timeout_us(NFC_I2C_INSTANCE, addr7, data, len, false, NFC_I2C_OP_TIMEOUT_US);
  return (res < 0) ? NFCTAG_NACK : NFCTAG_OK;
}

static bool tick_elapsed(uint32_t now_ms, uint32_t deadline_ms) { return ((int32_t)(now_ms - deadline_ms) >= 0); }

static bool st25_enforce_eh_enabled(ST25DV_Object_t* st, bool verbose, ST25DV_EH_CTRL* out_state) {
  ST25DV_EH_CTRL eh = {0};
  int32_t ret = NFCTAG_OK;

  for (uint32_t attempt = 0; attempt < (uint32_t)NFC_TUNE_EH_ENFORCE_RETRIES; attempt++) {
    ret = ST25DV_ReadEHCtrl_Dyn(st, &eh);
    if (ret == NFCTAG_OK && eh.EH_EN_Mode == ST25DV_ENABLE) {
      if (out_state != NULL) {
        *out_state = eh;
      }
      if (verbose && attempt > 0u) {
        printf("[OK] EH enable latched after %lu retry step(s)\n", (unsigned long)attempt);
      }
      return true;
    }

    ret = ST25DV_SetEHENMode_Dyn(st);
    if (ret != NFCTAG_OK) {
      // Datasheet behavior: writing EH_MODE=ACTIVE_AFTER_BOOT should force EH_EN=1.
      (void)ST25DV_WriteEHMode(st, ST25DV_EH_ACTIVE_AFTER_BOOT);
    }
    sleep_ms(NFC_TUNE_EH_ENFORCE_RETRY_MS);
  }

  ret = ST25DV_ReadEHCtrl_Dyn(st, &eh);
  if (ret == NFCTAG_OK) {
    if (out_state != NULL) {
      *out_state = eh;
    }
    if (verbose) {
      printf("[WARN] EH enable not latched: EH_EN=%u EH_ON=%u FIELD_ON=%u VCC_ON=%u\n",
             (unsigned)eh.EH_EN_Mode,
             (unsigned)eh.EH_on,
             (unsigned)eh.Field_on,
             (unsigned)eh.VCC_on);
    }
  } else if (verbose) {
    printf("[WARN] EH state read failed after enforce attempts: %ld\n", (long)ret);
  }
  return false;
}

static bool st25_rearm_eh_path(ST25DV_Object_t* st, bool verbose, ST25DV_EH_CTRL* out_state) {
  (void)ST25DV_ResetEHENMode_Dyn(st);
  sleep_ms(2);
  (void)ST25DV_WriteEHMode(st, ST25DV_EH_ACTIVE_AFTER_BOOT);
  sleep_ms(2);
  return st25_enforce_eh_enabled(st, verbose, out_state);
}
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
